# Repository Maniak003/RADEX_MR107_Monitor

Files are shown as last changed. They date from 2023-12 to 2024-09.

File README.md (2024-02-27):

<!DOCTYPE html>
<html lang="en" data-color-mode="auto" data-light-theme="light" data-dark-theme="dark">
  <head>
    <meta charset="utf-8">
  </head>
    <body class="logged-in env-production page-responsive page-blob" style="word-wrap: break-word;">
      <p> RADEX_MR107_Monitor.<br><b></p>
      <a href="https://github.com/Maniak003/RADEX_MR107_Monitor/wiki" rel="nofollow">
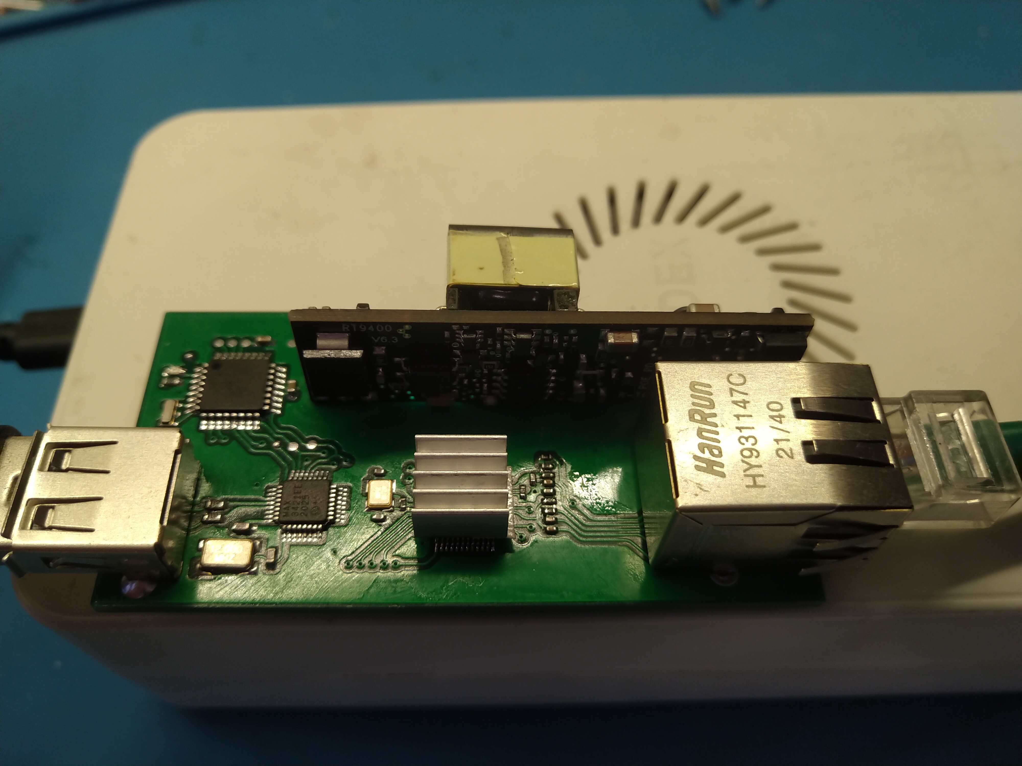
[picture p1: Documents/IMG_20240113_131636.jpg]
        
      </a>
      <a href="https://github.com/Maniak003/RADEX_MR107_Monitor/wiki" rel="nofollow">
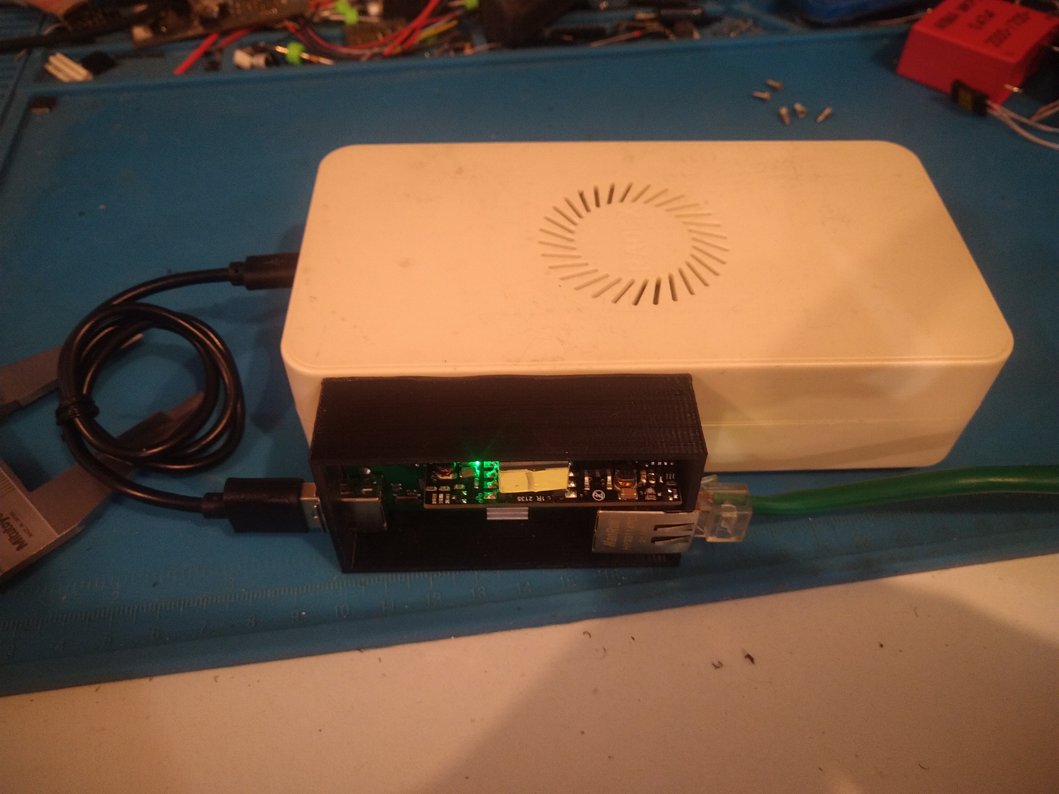
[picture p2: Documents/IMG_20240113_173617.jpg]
        
      </a>
      <a href="https://github.com/Maniak003/RADEX_MR107_Monitor/wiki" rel="nofollow">
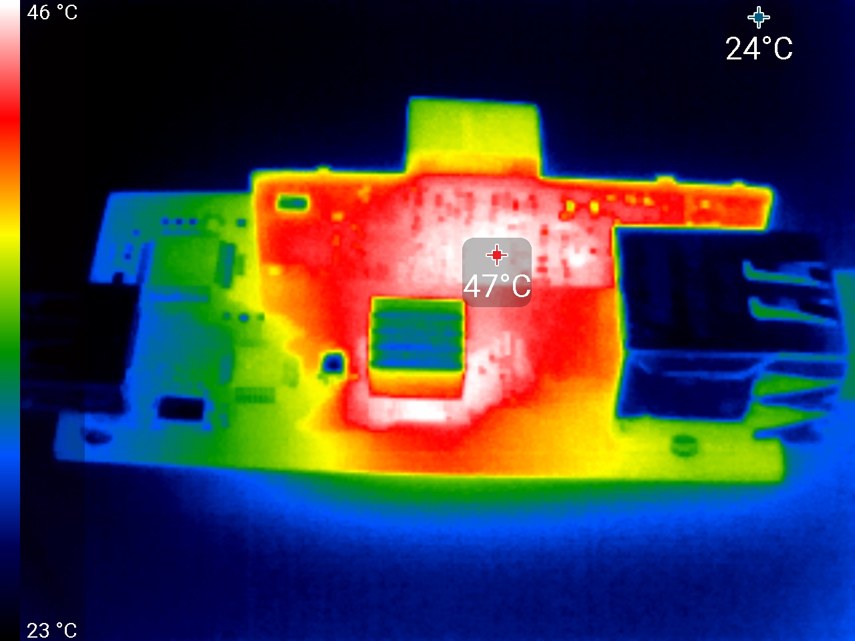
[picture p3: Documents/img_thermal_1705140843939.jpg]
        
      </a>
    </body>
</html>

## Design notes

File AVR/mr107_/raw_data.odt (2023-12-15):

Сырые данные при горячем старте:

7A FF 20 80 3A 00 83 04 00 00 A7 7B 04 08 00 00

30 00 00 00 08 00 28 00 B0 5C 0E 48 35 C4 6B 43

89 67 E2 41 3E F4 90 42 50 E7 F7 8F AE 00 00 00

8C 2E F2 42 40 E6 DD 42 35 C4 6B 43 00 00 00 00

D2 0D 00 00 00 00

Сырые данные при холодном старте:

1

7A FF 20 80 3A 00 83 04 00 00 A7 7B 04 08 00 00

30 00 00 00 09 00 00 00 00 00 08 00 00 00 00 00

89 67 E2 41 CA C3 80 42 C0 10 3C 99 AE 00 00 00

00 00 00 00 00 00 00 00 00 00 00 00 CA 45 47 47

35 38 00 00 00 00

2

7A FF 20 80 3A 00 83 04 00 00 A7 7B 04 08 00 00

30 00 00 00 00 00 00 00 00 00 08 00 00 00 00 00

62 06 D7 41 DB 69 00 42 C0 08 DD AF AE 00 00 00

00 00 00 00 00 00 00 00 00 00 00 00 30 5C 04 00

CE 36 00 00 00 00

Первое значение после 4-х часов.

7A FF 20 80 3A 00 83 04 00 00 A7 7B 04 08 00 00

30 00 00 00 09 00 01 00 40 38 0E 48 D9 2C F8 42

AE 53 B6 41 DD 30 ED 41 C0 10 3C 99 AE 00 00 00

00 00 58 43 D9 2C F8 42 D9 2C F8 42 D9 2C F8 42

B6 0A 00 00 00 00

Исходный реверс с https://ab-log.ru/smart-house/radon-monitoring

7A FF 20 80 3A 00 83 04 00 00 A7 7B 04 08 00 00

30 00 00 00 02 00 8D 00 00 E9 0E 48 D7 A1 EB 42

81 A6 E0 41 E6 F0 20 42 90 59 31 24 8E 00 00 00

1E 00 00 00 45 4B 82 42 90 16 1D 43 00 00 00 00

58 04 00 00 C7 5B

Данные от КРЦ Холодный старт:

7A FF 20 80 3A 00 83 04 00 00 A7 7B 04 08 00 00

30 00 00 00 03 00 00 00 00 00 08 00 00 00 00 00

3F 0D B9 41 AF AB 6F 42 A0 D3 6E 50 9A 00 00 00

00 00 00 03 00 00 00 00 00 00 00 00 71 A1 E6 7F

27 38 00 00 00 00

Горячий старт:

7A FF 20 80 3A 00 83 04 00 00 A7 7B 04 08 00 00

30 00 00 00 02 00 54 00 70 C7 0E C3 00 00 00 00

E4 0C AC 41 4C E4 40 42 A0 D3 6E 50 9A 00 00 00

6E DB 76 41 71 A1 E6 3F FE 8E 1E 42 00 00 00 00

CC 06 00 00 00 00

Температура, Влажность

Радон текущее, максимальное, минимальное, среднее.

Обратный отсчет в секундах

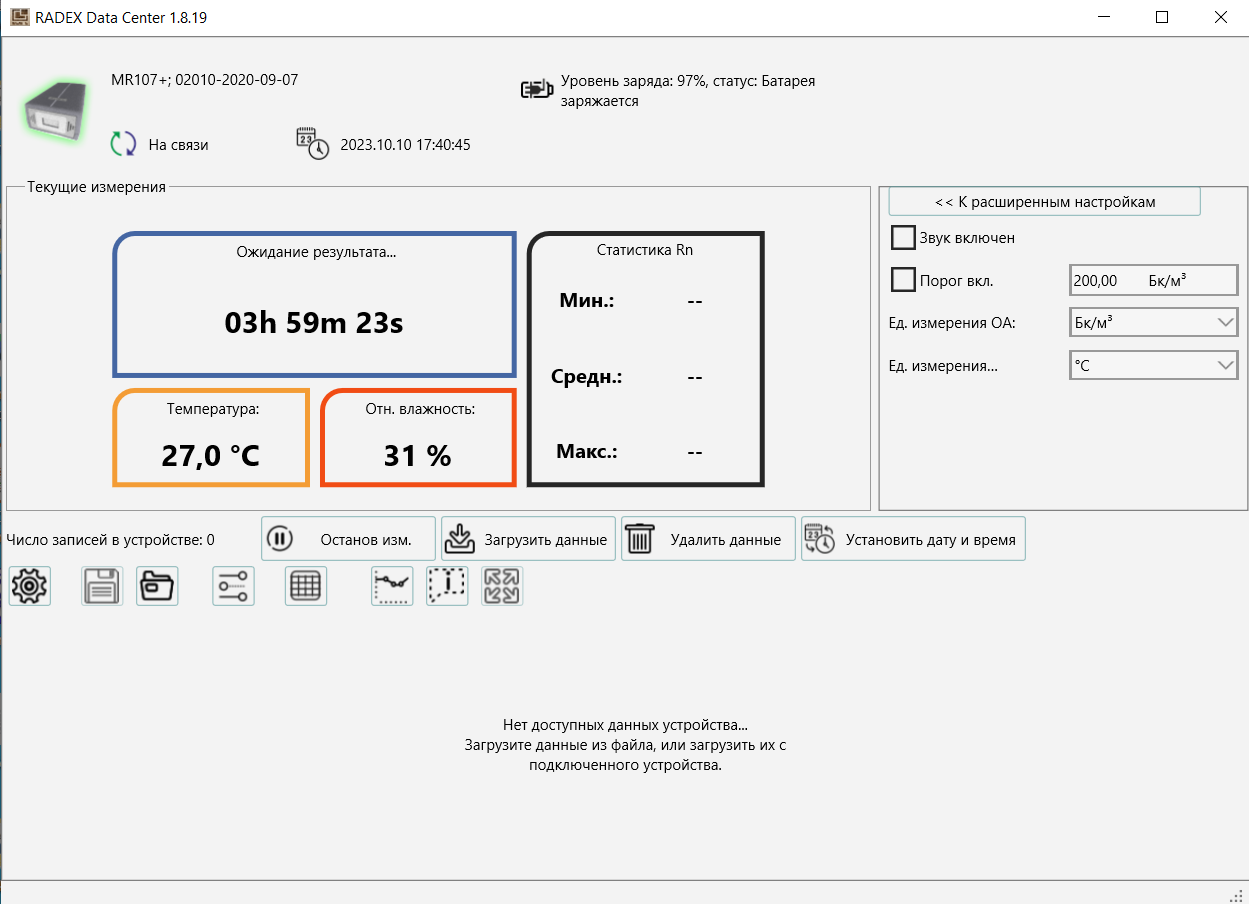
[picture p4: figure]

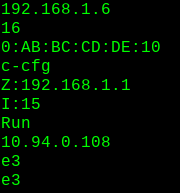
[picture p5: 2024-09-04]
Documents/ttl_uart_cfg.png

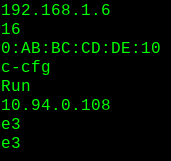
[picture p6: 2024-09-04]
Documents/ttl_uart_out.png

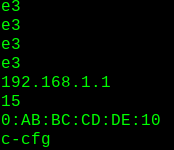
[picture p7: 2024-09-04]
Documents/ttl_uart_res.png

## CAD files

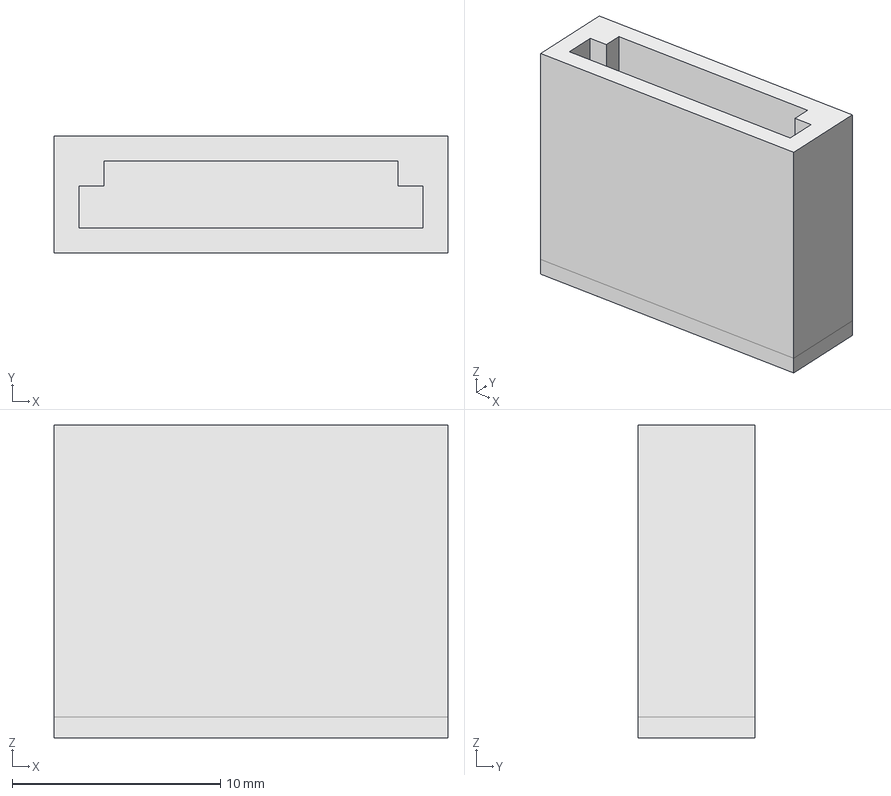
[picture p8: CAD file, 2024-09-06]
FreeCAD/bmp280Case.FCStd
18.9 x 5.60 x 15.0 mm

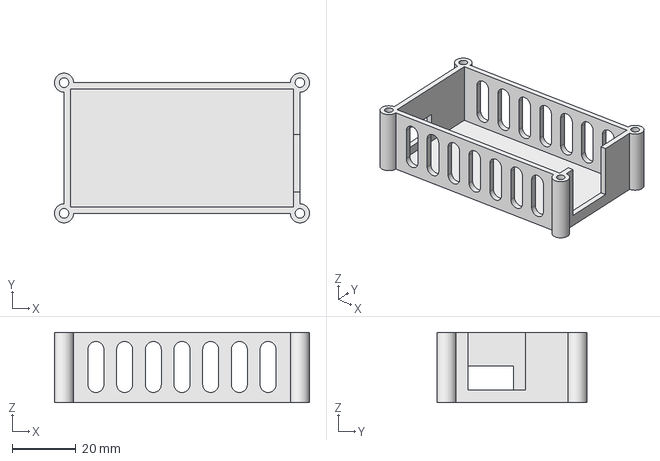
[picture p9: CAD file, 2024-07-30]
FreeCAD/mr107_box.FCStd
80.0 x 47.0 x 22.0 mm

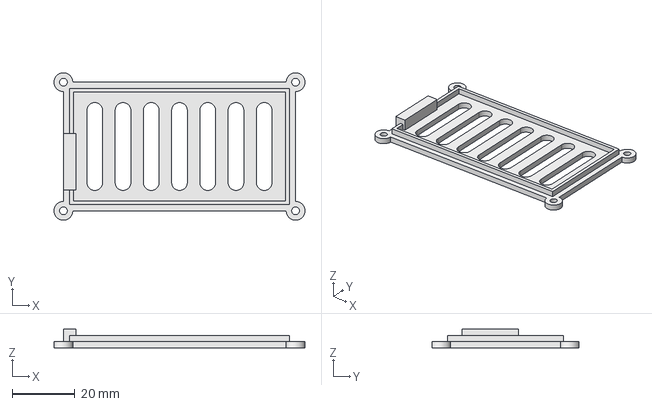
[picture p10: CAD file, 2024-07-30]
FreeCAD/mr107_cover.FCStd
80.0 x 47.0 x 6.00 mm

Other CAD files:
FreeCAD/bmp280Case.stl
FreeCAD/mr107_box.stl
FreeCAD/mr107_cover.stl

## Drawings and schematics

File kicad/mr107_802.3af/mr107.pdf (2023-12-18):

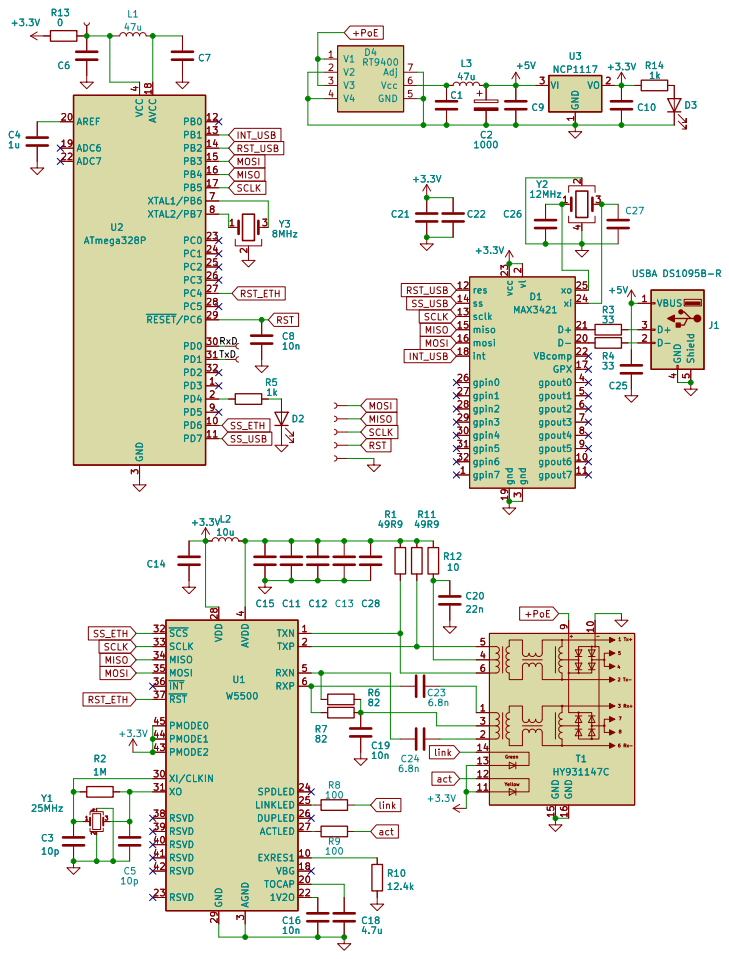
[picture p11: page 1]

RST SCLK MOSI MISO MISO

4 RSVD 40 RSVD 41 RSVD 42 PMODE2 43 PMODE1 44 PMODE0 45 RXN
2 TOCAP 20

3 XI/CLKIN 30 XO 31 ~{SCS} 32 SCLK 33 MISO 34 MOSI 35 ~{INT} 36 ~{RST} 37 RSVD 38 RSVD 39 AVDD

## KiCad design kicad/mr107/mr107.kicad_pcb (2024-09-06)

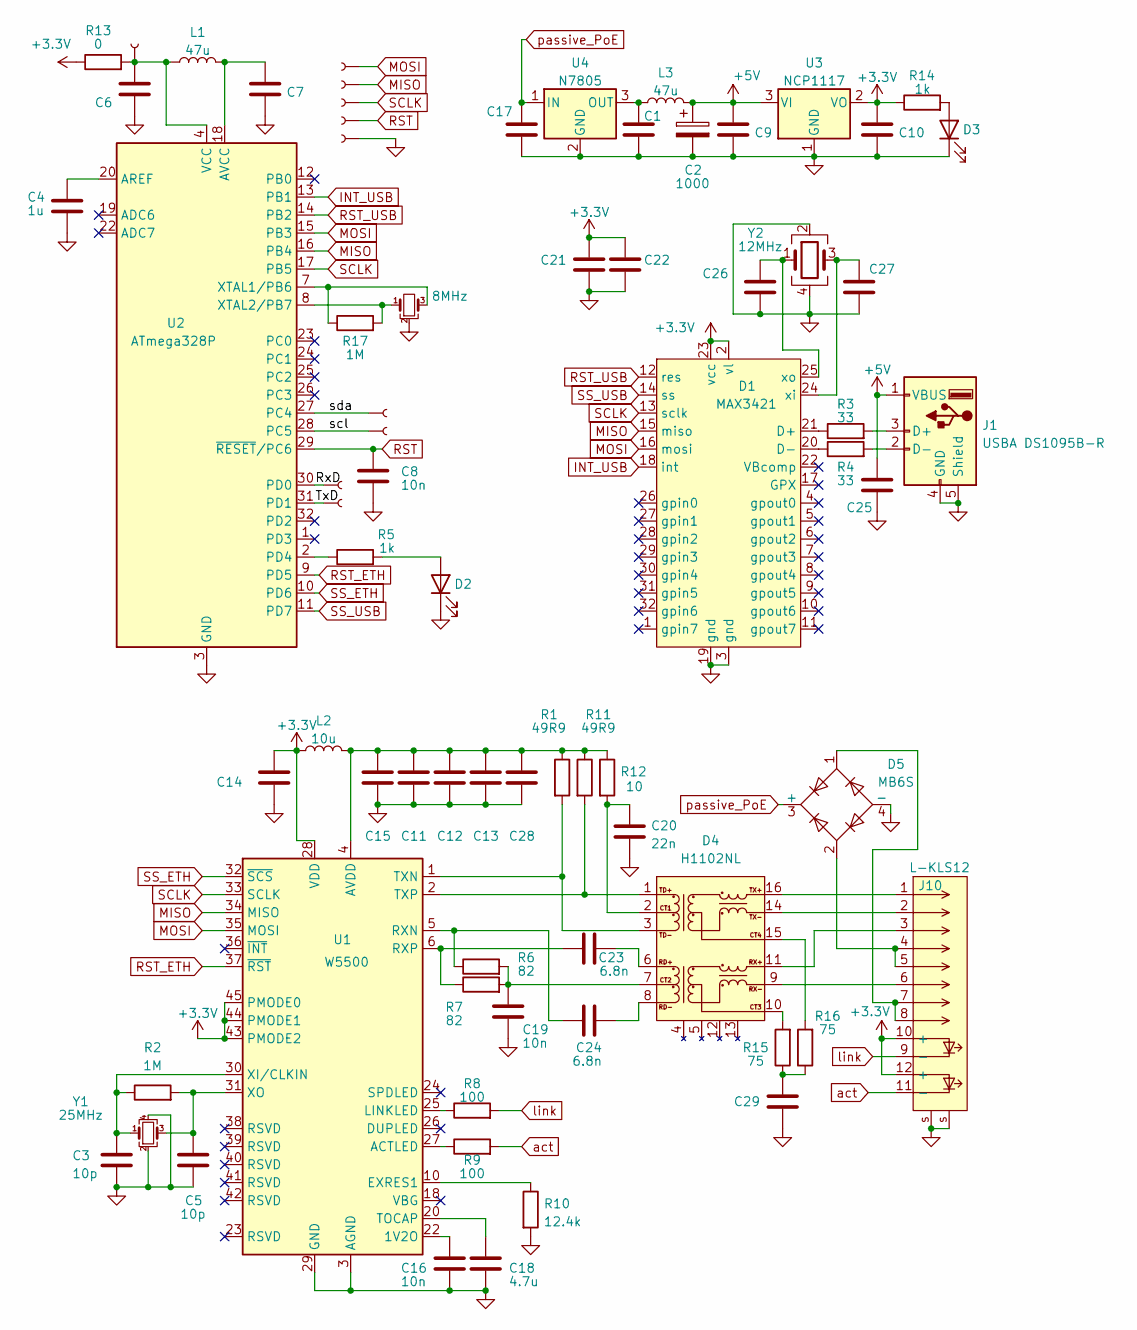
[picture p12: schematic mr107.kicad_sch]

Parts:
C1, C9, C10, C17, C25: 10u; C_0805_2012Metric
C2: 1000; CP_EIA-7343-15_Kemet-W
C3, C5: 10p; C_0402_1005Metric
C4, C6, C11, C12, C13, C14, C15, C21, C22: 1u; C_0603_1608Metric
C7: 10u; C_0603_1608Metric
C8: 10n; C_0603_1608Metric
C16, C19: 10n; C_0402_1005Metric
C18: 4.7u; C_0402_1005Metric
C20: 22n; C_0402_1005Metric
C23, C24: 6.8n; C_0402_1005Metric
C26, C27: 8p; C_0603_1608Metric
C28: 1u; C_0402_1005Metric
C29: 1n 2kV; C_1206_3216Metric
D1: MAX3421; PQFP-32_5x5mm_P0.5mm
D2, D3: LED; LED_0603_1608Metric
D4: H1102NL; H1102N
D5: MB6S; TO-269AA
J1: USBA DS1095B-R; USB_A_CONNFLY_DS1095-WNR0
J2: RxD; conn_mini
J3, J11, J12: mosi; conn_mini
J4: miso; conn_mini
J5: sclk; conn_mini
J6: reset; conn_mini
J7: gnd; conn_mini
J8: TxD; conn_mini
J9: PW; conn_mini
J10: L-KLS12; KLS12-108
L1, L3: 47u; L_0805_2012Metric
L2: 10u; L_0805_2012Metric
R1, R11: 49R9; R_0402_1005Metric
R2, R17: 1M; R_0402_1005Metric
R3, R4: 33; R_0603_1608Metric
R5, R14: 1k; R_0603_1608Metric
R6, R7: 82; R_0402_1005Metric
R8, R9: 100; R_0603_1608Metric
R10: 12.4k; R_0402_1005Metric
R12: 10; R_0402_1005Metric
R13: 0; R_0603_1608Metric
R15, R16: 75; R_0603_1608Metric
U1: W5500; LQFP-48_7x7mm_P0.5mm
U2: ATmega328P; TQFP-32_7x7mm_P0.8mm
U3: NCP1117; SOT-223-3_TabPin2
U4: N7805; TO-220-3_Vertical
Y1: 25MHz; Crystal_SMD_3225-4Pin_3.2x2.5mm
Y2: 12MHz; Crystal_SMD_0603-4Pin_6.0x3.5mm
Y3: 8MHz; Resonator_SMD_Murata_CSTxExxV-3Pin_3.0x1.1mm

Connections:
+3.3V: C10.1, C14.1, C21.1, C22.1, D1.2 (vl), D1.23 (vcc), J10.10 (+), J10.12 (+), L2.1, R13.1, R14.1, U1.28 (VDD), U1.43 (PMODE2), U1.44 (PMODE1), U1.45 (PMODE0), U3.2 (VO)
+5V: C2.1, C9.1, C25.1, J1.1 (VBUS), L3.2, U3.3 (VI)
/RxD: J2.1, U2.30 (PD0)
/TxD: J8.1, U2.31 (PD1)
/scl: J12.1, U2.28 (PC5)
/sda: J11.1, U2.27 (PC4)
GND: C1.2, C2.2, C3.2, C4.2, C5.2, C6.2, C7.2, C8.2, C9.2, C10.2, C11.2, C12.2, C13.2, C14.2, C15.2, C16.2, C17.2, C18.2, C19.2, C20.2, C21.2, C22.2, C25.2, C26.2, C27.2, C28.2, C29.2, D1.3 (gnd), D1.19 (gnd), D2.1 (K), D3.1 (K), D5.4 (-), J1.4 (GND), J1.5 (Shield), J7.1, J10.s, R10.2, U1.3 (AGND), U1.9 (AGND), U1.14 (AGND), U1.16 (AGND), U1.19 (AGND), U1.29 (GND), U1.48 (AGND), U2.3 (GND), U2.5 (GND), U2.21 (GND), U3.1 (GND), U4.2 (GND), Y1.2, Y1.4, Y2.2, Y2.4, Y3.2
INT_USB: D1.18 (int), U2.13 (PB1)
MISO: D1.15 (miso), J4.1, U1.34 (MISO), U2.16 (PB4)
MOSI: D1.16 (mosi), J3.1, U1.35 (MOSI), U2.15 (PB3)
unnamed: C1.1, L3.1, U4.3 (OUT)
unnamed: C3.1, R2.1, U1.30 (XI/CLKIN), Y1.1
unnamed: C4.1, U2.20 (AREF)
unnamed: C5.1, R2.2, U1.31 (XO), Y1.3
unnamed: C6.1, J9.1, L1.1, R13.2, U2.4 (VCC), U2.6 (VCC)
unnamed: C7.1, L1.2, U2.18 (AVCC)
unnamed: C11.1, C12.1, C13.1, C15.1, C28.1, L2.2, R1.1, R11.1, R12.1, U1.4 (AVDD), U1.8 (AVDD), U1.11 (AVDD), U1.15 (AVDD), U1.17 (AVDD), U1.21 (AVDD)
unnamed: C16.1, U1.22 (1V2O)
unnamed: C18.1, U1.20 (TOCAP)
unnamed: C19.1, D4.7, R6.2, R7.2
unnamed: C20.1, D4.2, R12.2
unnamed: C23.1, R7.1, U1.6 (RXP)
unnamed: C23.2, D4.6
unnamed: C24.1, R6.1, U1.5 (RXN)
unnamed: C24.2, D4.8
unnamed: C26.1, D1.25 (xo), Y2.1
unnamed: C27.1, D1.24 (xi), Y2.3
unnamed: C29.1, R15.1, R16.1
unnamed: D1.20 (D-), R4.1
unnamed: D1.21 (D+), R3.1
unnamed: D2.2 (A), R5.2
unnamed: D3.2 (A), R14.2
unnamed: D4.1, R11.2, U1.2 (TXP)
unnamed: D4.3, R1.2, U1.1 (TXN)
unnamed: D4.9, J10.6
unnamed: D4.10, R15.2
unnamed: D4.11, J10.3
unnamed: D4.14, J10.2
unnamed: D4.15, R16.2
unnamed: D4.16, J10.1
unnamed: D5.1, J10.7, J10.8
unnamed: D5.2, J10.4, J10.5
unnamed: J1.2 (D-), R4.2
unnamed: J1.3 (D+), R3.2
unnamed: R5.1, U2.2 (PD4)
unnamed: R8.1, U1.25 (LINKLED)
unnamed: R9.1, U1.27 (ACTLED)
unnamed: R10.1, U1.10 (EXRES1)
unnamed: R17.1, U2.7 (XTAL1/PB6), Y3.3
unnamed: R17.2, U2.8 (XTAL2/PB7), Y3.1
RST: C8.1, J6.1, U2.29 (~RESET/PC6)
RST_ETH: U1.37 (~RST), U2.9 (PD5)
RST_USB: D1.12 (res), U2.14 (PB2)
SCLK: D1.13 (sclk), J5.1, U1.33 (SCLK), U2.17 (PB5)
SS_ETH: U1.32 (~SCS), U2.10 (PD6)
SS_USB: D1.14 (ss), U2.11 (PD7)
act: J10.11 (-), R9.2
link: J10.9 (-), R8.2
passive_PoE: C17.1, D5.3 (+), U4.1 (IN)

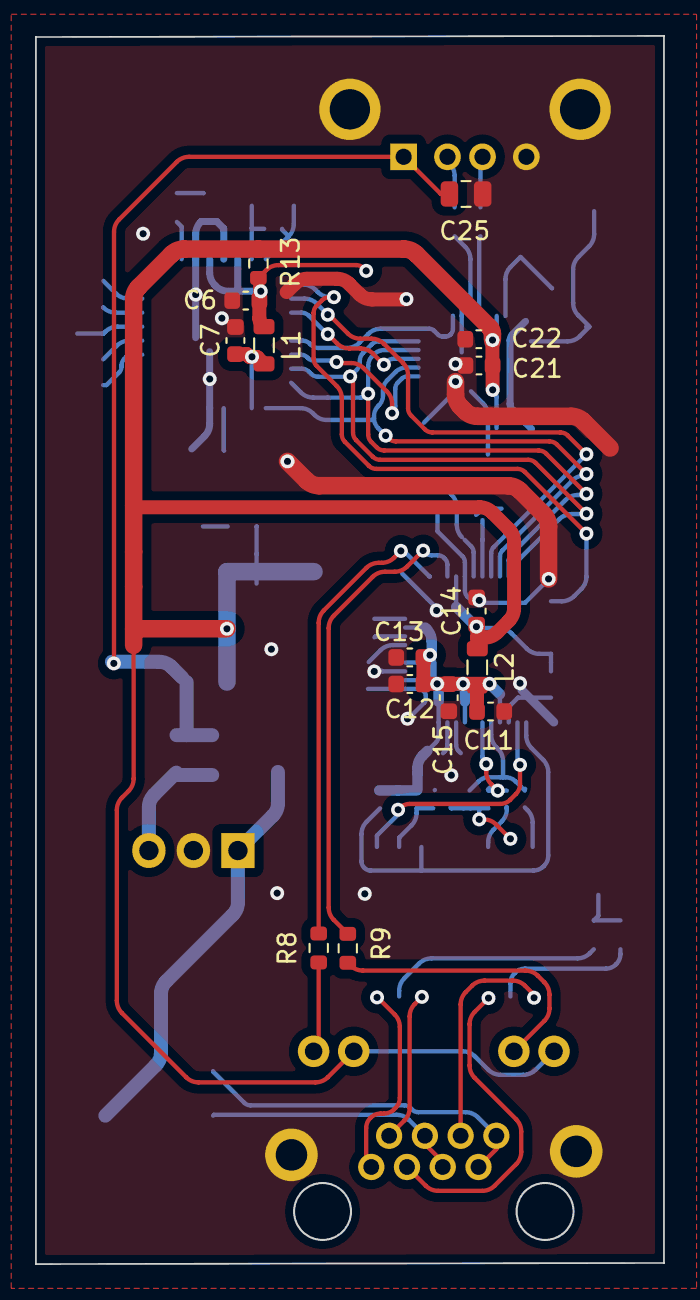
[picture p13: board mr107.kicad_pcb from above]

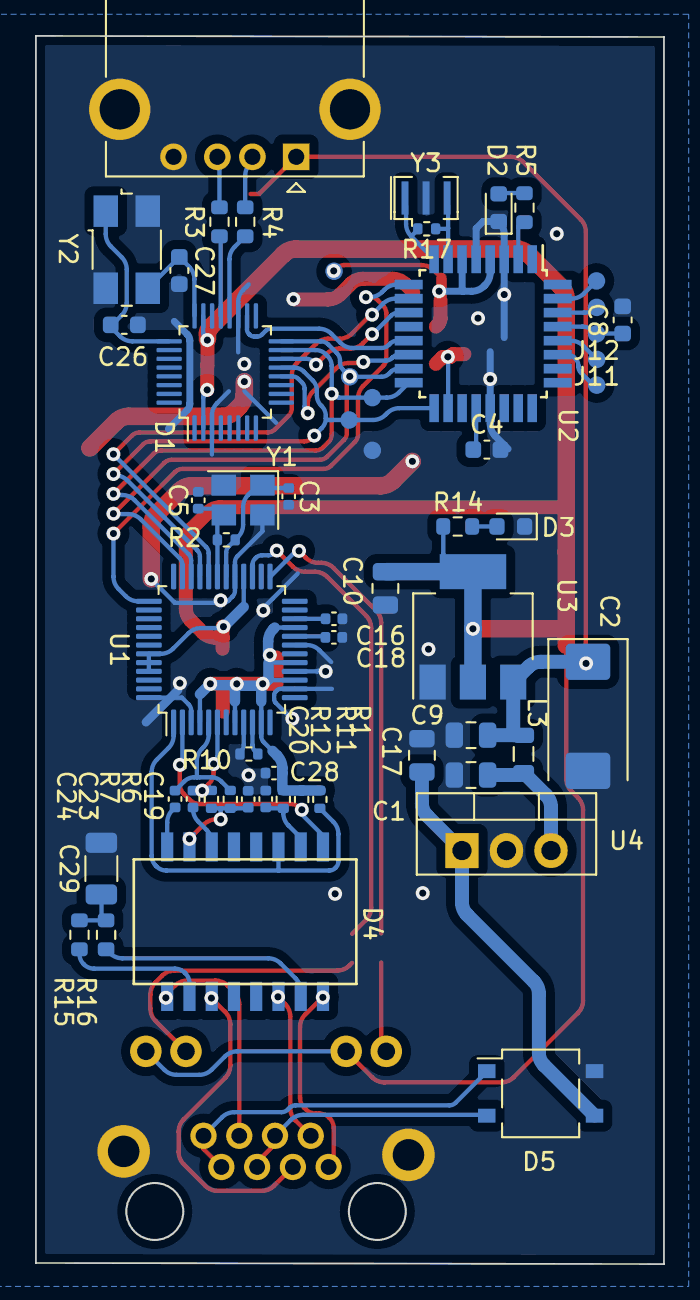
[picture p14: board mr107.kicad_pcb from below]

Board: 2 copper layers, 35.8 x 70.1 mm, 73 parts (58 on the bottom side), 59 nets.

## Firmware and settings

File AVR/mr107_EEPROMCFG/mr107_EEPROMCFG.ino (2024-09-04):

/*
Монитор для RADEX MR107+ (VID: abba PID: a104) с регистрацией в zabbix

Для работы с BMP280 используется библиотека BMx280MI
 
Компилировать как MiniCore 3.3v 8MHz
Прошивать:  avrdude -B 125kHz  -p m328p -c usbasp  -U flash:w:./file.hex:i -Uefuse:w:0xFD:m -Uhfuse:w:0xDA:m -Ulfuse:w:0xFF:m
            avrdude -p m328p -c stk500pp -P /dev/ttyUSB0 -U flash:w:./$1:i -Uefuse:w:0xFD:m -Uhfuse:w:0xDA:m -Ulfuse:w:0xFF:m

Сырые данные при горячем старте:

7A FF 20 80 3A 00 83 04 00 00 A7 7B 04 08 00 00
30 00 00 00 08 00 28 00 B0 5C 0E 48 35 C4 6B 43
89 67 E2 41 3E F4 90 42 50 E7 F7 8F AE 00 00 00
8C 2E F2 42 40 E6 DD 42 35 C4 6B 43 00 00 00 00
D2 D0 00 00 00 00

Сырые данные при холодном старте:

7A FF 20 80 3A 00 83 04 00 00 A7 7B 04 08 00 00
30 00 00 00 09 00 00 00 00 00 08 00 00 00 00 00
89 67 E2 41 CA C3 80 42 C0 10 3C 99 AE 00 00 00
00 00 00 00 00 00 00 00 00 00 00 00 CA 45 47 47
35 38 00 00 00 00

*/

#define MAGICKKEY 0x1234              // Magick key
#define USBHOSTSS 7                   // Need relocate from 10 to 7 on USB host shield.
#define ZABBIXPORT 10051              // Zabbix server Port
#define ZABBIXADDR {192,168,1,1}  // Zabbix server IP, comma separated
#define ZABBIXMAXLEN 128
#define ZABBIXAGHOST "MR"             // Zabbix item's host name
#define ZABBIXSENDPERIOD 600          // Period in secoonds
#define ZABBRADONKEY "rad"
#define ZABBTEMPERATUREKEY "tem"
#define ZABBHUMMIDITYKEY "hum"
#define ZABBPRESSUREKEY "pres"
#define ZABBTEMPBMP280EKEY "Tp"
#define BUFFERSIZE 70
#define wdt_on true
#define LED_CHK 4
#define ETH_RESET 5
#define USB_RESET 10
#define MACADDR { 0x00, 0xAB, 0xBC, 0xCD, 0xDE, 0x0A }
#define SERIAL_OUT

//#include <Wire.h>
#include <EEPROM.h>
#include <cdcacm.h>
#include <usbhub.h>
#define PIN_SPI_SS_ETHERNET_LIB 6
#include <Ethernet.h>

#include <SPI.h>
#if wdt_on
#include <avr/wdt.h>
#endif

#ifdef ZABBTEMPBMP280EKEY
#include <BMx280I2C.h>
#define I2C_ADDRESS 0x76
BMx280I2C bmx280(I2C_ADDRESS);
#endif

struct cfgData {
  uint16_t mk;
  IPAddress zabbSrv;
  uint8_t keyID;
} configData;

//  ID abba:a104
union {
  uint32_t u32;
  float flt;
} mrdata;

uint16_t rcvd = BUFFERSIZE;
uint8_t  rec_buffer[BUFFERSIZE + 1], errorCount = 0, errorEthCount = 0;
String str;
unsigned long curTime = 0, tmpTime;
bool bmp280active = false;

#if defined(WIZ550io_WITH_MACADDRESS) // Use assigned MAC address of WIZ550io
  ;
#else
  byte mac[] = MACADDR;
#endif
int len;
uint8_t res[ZABBIXMAXLEN];
EthernetClient client;

void sendToZabbix(String key, float val)
{
  str = "";
  str = str + "{\"request\":\"sender data\",\"data\":[{\"host\":\"";
  str = str + ZABBIXAGHOST + configData.keyID;
  str = str + "\",\"key\":\""; 
  str = str + key;
  str = str + "\",\"value\":\"";
  str = str + val;
  str = str + "\"}]}";
  len = str.length();
  res[0] = 'Z';
  res[1] = 'B';
  res[2] = 'X';
  res[3] = 'D';
  res[4] = 0x01;
  res[5] = str.length();
  res[6] = 0;
  res[7] = 0;
  res[8] = 0;
  res[9] = 0;
  res[10] = 0;
  res[11] = 0;
  res[12] = 0;
  str.getBytes(&(res[13]), ZABBIXMAXLEN - 12);
  len = len + 13;
  if (client.connect(configData.zabbSrv, ZABBIXPORT)) {
    errorEthCount = 0;
    client.write(res, len);
  } else {
    //Serial.println("Eth fail");
    digitalWrite(LED_CHK, HIGH);
    curTime = 0;
    if (errorEthCount++ > 3) {
      for(;;);
    }
  }
  client.stop();     
}

class ACMAsyncOper : public CDCAsyncOper {
public:
    uint8_t OnInit(ACM *pacm);
};

uint8_t ACMAsyncOper::OnInit(ACM *pacm) {
    uint8_t rcode;
    // Set DTR = 1 RTS=1
    rcode = pacm->SetControlLineState(3);

    if (rcode) {
        //ErrorMessage<uint8_t>(PSTR("SCS"), rcode);
        return rcode;
    }

    LINE_CODING  lc;
    lc.dwDTERate  = 115200;
    lc.bCharFormat  = 0;
    lc.bParityType  = 0;
    lc.bDataBits  = 8;
    rcode = pacm->SetLineCoding(&lc);
    //if (rcode)
        //ErrorMessage<uint8_t>(PSTR("SetLineCoding"), rcode);
    return rcode;
}

USB     Usb;
ACMAsyncOper  AsyncOper;
ACM           Acm(&Usb, &AsyncOper);
uint8_t snd_buffer[] = {0x7b, 0xff, 0x20, 0x00, 0x06, 0x00, 0x83, 0x04, 0x00, 0x00, 0xda, 0xfb, 0x04, 0x08, 0x0c, 0x00, 0xef, 0xf7};

void setup() {
  #if wdt_on
    MCUSR &= ~(1 << WDRF);
    wdt_disable();
  #endif
  pinMode(LED_CHK, OUTPUT);
  digitalWrite(LED_CHK, HIGH);
  pinMode(ETH_RESET, OUTPUT);
  digitalWrite(ETH_RESET, LOW);
  digitalWrite(ETH_RESET, HIGH);
  pinMode(PIN_SPI_SS_ETHERNET_LIB, OUTPUT);
  digitalWrite(PIN_SPI_SS_ETHERNET_LIB, HIGH);
  
  /* Read EEPROM */
  EEPROM.get(0, configData);
  if (configData.mk != MAGICKKEY) {
    configData.mk = MAGICKKEY;
    configData.zabbSrv = ZABBIXADDR;
    configData.keyID = mac[5];
    EEPROM.put(0, configData);
  }

  Serial.begin( 9600 );
  while (!Serial);
  Serial.println(configData.zabbSrv);
  Serial.println(configData.keyID);
  for (int i= 0; i < 6; i++) {
    Serial.print(mac[i], HEX);
    if (i < 5)
      Serial.print(":");
  }
  Serial.println();
  Serial.println("c-cfg");
  int waitSerial = 200;
  while (Serial.available() == 0 && waitSerial-- > 0) {
    delay(10);
  }
  /* Запуск конфигуратора */
  if(Serial.available() > 0) {
    if (Serial.read() == 'c') {
      //Serial.flush();
      while (Serial.available() > 0) {
        Serial.read();
      }
      Serial.print("Z:");
      String tmp = "";
      uint8_t tmpChr;
      //byte ipADDR[4] = {0,0,0,0};
      uint8_t addrIDX = 0;
      /* Воод IP адреса сервера zabbix */
      while(1) {
        if(Serial.available() > 0) {
          tmpChr = Serial.read();
          Serial.print((char) tmpChr);
          if (tmpChr == 46) {                 // .
            configData.zabbSrv[addrIDX++] = tmp.toInt();
            tmp = "";
          } else if ((tmpChr == 13) || (tmpChr == 10)) {          // \n
            configData.zabbSrv[addrIDX++] = tmp.toInt();
            Serial.println();
            break;
          } else {
            tmp = tmp + (char) tmpChr;
          }
        }
      }
      Serial.print("I:");
      tmp = "";
      /* ID контроллера */
      while(1) {
        if(Serial.available() > 0) {
          tmpChr = Serial.read();
          Serial.print((char) tmpChr);
          if ((tmpChr == 13) || (tmpChr == 10)) {
            configData.keyID = tmp.toInt();
            Serial.println();
            break;
          } else {
            tmp = tmp + (char) tmpChr;
          }
        }
      }
      //configData.zabbSrv = IPAddress(ipADDR);
      EEPROM.put(0, configData);
    }
  }
  Serial.println("Run");

  pinMode(USBHOSTSS, OUTPUT);
  digitalWrite(USBHOSTSS, HIGH); // Disable SS fo USB host.
  pinMode(USB_RESET, OUTPUT);
  digitalWrite(USB_RESET, LOW);
  digitalWrite(USB_RESET, HIGH);
  #if wdt_on
    wdt_enable(WDTO_8S);
  #endif
  #ifdef ZABBTEMPBMP280EKEY
  if (bmx280.begin()) {
    bmx280.resetToDefaults();
    bmx280.writeOversamplingPressure(BMx280MI::OSRS_P_x16);
    bmx280.writeOversamplingTemperature(BMx280MI::OSRS_T_x16);
    bmp280active = true;
  }
  #endif
  Ethernet.init(PIN_SPI_SS_ETHERNET_LIB);
  #if defined(WIZ550io_WITH_MACADDRESS) // Use assigned MAC address of WIZ550io
    if (Ethernet.begin() == 0) {
  #else
    if (Ethernet.begin(mac) == 0) {
  #endif
      for(;;);
    }
  //Serial.print("IP:");
  Serial.println(Ethernet.localIP());
  if (Usb.Init() == -1) {
    //Serial.println("e2");
      //while ( 1 );
  }
  //digitalWrite(LED_CHK, LOW);
  //delay( 200 );
}

void loop() {
  uint8_t rcode;

  Usb.Task();
  #if wdt_on
    wdt_reset();
  #endif
  if( Acm.isReady()) {
    digitalWrite(LED_CHK, LOW);
    errorCount = 0;
    tmpTime = millis();
    if (curTime == 0 || tmpTime - curTime > (unsigned long) ZABBIXSENDPERIOD * 1000 ) {
      curTime = tmpTime;
      rcode = Acm.SndData(sizeof(snd_buffer), snd_buffer);
      //if (rcode)
        //ErrorMessage<uint8_t>(PSTR("SndData"), rcode);
      delay(50);
      rcvd = BUFFERSIZE;
      //for (uint16_t i = 0; i < sizeof(rec_buffer); i++)
      //  rec_buffer[i] = 0;
      memset(rec_buffer, 0, sizeof(rec_buffer));
      rcode = Acm.RcvData(&rcvd, rec_buffer);
       if (rcode && rcode != hrNAK) {
          //ErrorMessage<uint8_t>(PSTR("Ret"), rcode);
       } else {
          if( rcvd == BUFFERSIZE ) {
            /* Радон */
            uint16_t X24 = (uint16_t) rec_buffer[25] << 8 | (uint16_t) rec_buffer[24];
            mrdata.u32 = (uint32_t) rec_buffer[31] << 24 | (uint32_t) rec_buffer[30] << 16 | (uint32_t) rec_buffer[29] << 8 | (uint32_t) rec_buffer[28];
            if (X24 > 0 ) {  // Холодный старт
              if (mrdata.flt > 30) {  // значение меньше 30Бк
                sendToZabbix(ZABBRADONKEY, mrdata.flt);
              } else {
                sendToZabbix(ZABBRADONKEY, 30.0);
              }
            }
            /* Температура */
            #ifdef ZABBTEMPERATUREKEY
            mrdata.u32 = (uint32_t) rec_buffer[35] << 24 | (uint32_t) rec_buffer[34] << 16 | (uint32_t) rec_buffer[33] << 8 | (uint32_t) rec_buffer[32];
            sendToZabbix(ZABBTEMPERATUREKEY, mrdata.flt);
            #endif
            /* Влажность */
            #ifdef ZABBHUMMIDITYKEY
            mrdata.u32 = (uint32_t) rec_buffer[39] << 24 | (uint32_t) rec_buffer[38] << 16 | (uint32_t) rec_buffer[37] << 8 | (uint32_t) rec_buffer[36];
            sendToZabbix(ZABBHUMMIDITYKEY, mrdata.flt);
            #endif
            /* Давление и температура с bmp280 */
            #if defined(ZABBPRESSUREKEY) && defined(ZABBTEMPBMP280EKEY)
            if (bmp280active && bmx280.measure()) {
              while (!bmx280.hasValue());
              sendToZabbix(ZABBPRESSUREKEY, bmx280.getPressure());
              //sendToZabbix(ZABBTEMPBMP280EKEY, bmx280.getTemperature());
            }
            #endif
          } else {
            delay(1000);
            curTime = 0;    // Обнулим интервал в случае ошибки, что бы ускорить перезапрос данных.
          }
       }
    }
  } else {
    /*if (bmp280active && bmx280.measure()) {
      while (!bmx280.hasValue());
      Serial.println(bmx280.getPressure());
    }*/
    /* Сюда попадем при неудачной попытке подключить mr107 */
    Serial.println("e3");
    digitalWrite(LED_CHK, HIGH);
    curTime = 0;    // Обнулим интервал в случае ошибки, что бы ускорить перезапрос данных.
    if (errorCount++ > 20) {
      for(;;);
    }
    delay(1000);
  }
}

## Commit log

2023-12-15 изменено: AVR/mr107_/mr107_.ino новый файл: kicad/mr107/bom/ibom.html изменено: kicad/mr107/gerber/Border.gbr изменено: kicad/mr107/gerber/Bottom.gbr изменено: kicad/mr107/gerber/MaskBottom.gbr измен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
    [mr107.kicad_pcb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]
2023-12-15 изменено: kicad/mr107/bom/ibom.html
2023-12-18 переименовано: AVR/mr107_/W5100_Layout_Guide.pdf -> Documents/W5100_Layout_Guide.pdf переименовано: AVR/mr107_/W5100_Ref_sch_MAG_R2.1.pdf -> Documents/W5100_Ref_sch_MAG_R2.1.pdf
2023-12-18 новый файл: kicad/mr107_802.3af/bom/ibom.html новый файл: kicad/mr107_802.3af/fp-info-cache новый файл: kicad/mr107_802.3af/gerber/Border.gbr новый файл: kicad/mr107_802.3af/gerber/Bottom.gbr новый ф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
    [mr107.kicad_pcb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]
2023-12-18 удалено: kicad/mr107_802.3af/gerber/Border.gbr удалено: kicad/mr107_802.3af/gerber/Bottom.gbr удалено: kicad/mr107_802.3af/gerber/MaskBottom.gbr удалено: kicad/mr107_802.3af/gerber/MaskTop.gbr удален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
    [mr107.kicad_pcb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]
2023-12-18 изменено: kicad/mr107_802.3af/bom/ibom.html
2023-12-19 удалено: kicad/mr107_802.3af/mr107-backups/mr107-2023-12-09_163958.zip удалено: kicad/mr107_802.3af/mr107-backups/mr107-2023-12-18_154055.zip изменено: kicad/mr107_802.3af/mr107.kicad_prl изменено: k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
    [mr107.kicad_sch]
2023-12-29 изменено: kicad/mr107/bom/ibom.html удалено: kicad/mr107/gerber/Border.gbr удалено: kicad/mr107/gerber/Bottom.gbr удалено: kicad/mr107/gerber/MaskBottom.gbr удалено: kicad/mr107/gerber/MaskTop.gbr уд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
    [mr107.kicad_pcb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]
2023-12-31 новый файл: AVR/library/Ethernet/AUTHORS новый файл: AVR/library/Ethernet/README.adoc новый файл: AVR/library/Ethernet/examples/AdvancedChatServer/AdvancedChatServer.ino новый файл: AVR/library/Ether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
2024-01-16 изменено: AVR/mr107_/mr107_.ino удалено: kicad/mr107/mr107-backups/mr107-2023-12-07_190314.zip
2024-01-16 изменено: AVR/mr107_/mr107_.ino.eightanaloginputs.hex изменено: AVR/mr107_/mr107_.ino.with_bootloader.eightanaloginputs.hex
2024-02-27 изменено: AVR/mr107_/mr107_.ino
2024-02-27 удалено: AVR/mr107_/mr107_.ino.eightanaloginputs.hex удалено: AVR/mr107_/mr107_.ino.with_bootloader.eightanaloginputs.hex
2024-02-27 новый файл: Documents/IMG_20240113_131636.jpg новый файл: Documents/IMG_20240113_173617.jpg новый файл: Documents/img_thermal_1705140843939.jpg
2024-03-08 изменено: AVR/mr107_/mr107_.ino изменено: kicad/mr107_802.3af/mr107.kicad_prl
2024-07-30 изменено: AVR/mr107_/mr107_.ino удалено: kicad/mr107/mr107-backups/mr107-2023-12-09_164959.zip удалено: kicad/mr107/mr107-backups/mr107-2023-12-09_165959.zip удалено: kicad/mr107/mr107-backups/mr107-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
    [mr107.kicad_sch]
2024-07-30 новый файл: AVR/mr107_EEPROMCFG/mr107_EEPROMCFG.ino
2024-07-30 новый файл: FreeCAD/mr107_box.FCStd новый файл: FreeCAD/mr107_box.stl новый файл: FreeCAD/mr107_cover.FCStd новый файл: FreeCAD/mr107_cover.stl
    [mr107_box.FCStd, mr107_box.stl, mr107_cover.FCStd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]
2024-07-30 изменено: AVR/mr107_EEPROMCFG/mr107_EEPROMCFG.ino
2024-07-31 изменено: AVR/mr107_/write-avr.sh изменено: AVR/mr107_/write-avr.sh~ изменено: AVR/mr107_EEPROMCFG/mr107_EEPROMCFG.ino изменено: kicad/mr107_802.3af/bom/ibom.html
2024-08-02 изменено: AVR/mr107_EEPROMCFG/mr107_EEPROMCFG.ino изменено: kicad/mr107/mr107.kicad_sch
    [mr107.kicad_sch]
2024-08-02 изменено: AVR/mr107_EEPROMCFG/mr107_EEPROMCFG.ino удалено: kicad/mr107/mr107-backups/mr107-2023-12-11_173003.zip
2024-08-02 удалено: kicad/mr107/mr107-backups/mr107-2023-12-12_103509.zip удалено: kicad/mr107/mr107-backups/mr107-2023-12-12_104452.zip удалено: kicad/mr107/mr107-backups/mr107-2023-12-12_105008.zip удалено: k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
    [mr107.kicad_pcb, mr107.kicad_sch]
2024-08-30 удалено: kicad/mr107/mr107-backups/mr107-2023-12-12_110331.zip
2024-09-03 изменено: kicad/mr107/gerber/mr107.zip изменено: kicad/mr107/mr107.kicad_pcb изменено: kicad/mr107/mr107.kicad_sch
    [mr107.kicad_pcb, mr107.kicad_sch]
2024-09-04 изменено: AVR/mr107_EEPROMCFG/mr107_EEPROMCFG.ino новый файл: Documents/N78.PDF новый файл: Documents/ttl_uart_cfg.png новый файл: Documents/ttl_uart_out.png
2024-09-04 новый файл: Documents/ttl_uart_res.png
2024-09-06 изменено: kicad/mr107/fp-info-cache изменено: kicad/mr107/mr107.kicad_pcb изменено: kicad/mr107/mr107.kicad_prl изменено: kicad/mr107/mr107.kicad_sch
    [mr107.kicad_pcb, mr107.kicad_sch]
2024-09-06 новый файл: FreeCAD/bmp280Case.FCStd новый файл: FreeCAD/bmp280Case.stl
    [bmp280Case.FCStd, bmp280Case.stl]
